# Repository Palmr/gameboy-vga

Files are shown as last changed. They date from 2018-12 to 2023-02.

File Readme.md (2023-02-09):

# FPGA Game Boy Framebuffer

My attempts at hooking in to the Game Boy LCD cable to sniff frame data.

Currently only looking at the Game Boy Pocket as I have one with screen rot and would ideally like to add other output options or replace the screen with something else.

## Requirements

Currently running off an [Lattice Semi](http://www.latticesemi.com) FPGA on a [TinyFPGA BX](https://github.com/tinyfpga/TinyFPGA-BX).

After cloning this repository make sure to pull in the submodule for building/flashing the RTL

```bash
git submodule update --init
```

This should pull in my forked version of the excellent [fpga-tools](https://github.com/pwmarcz/fpga-tools/) submodule by [Paweł Marczewski](https://github.com/pwmarcz).

Required software:

- [Project IceStorm](http:///www.clifford.at/icestorm/)
- [iceBurn](https://github.com/davidcarne/iceBurn)
- GTKWave (for `make sim` target)

## RTL

Experiments documented in [see the rtl/exploration/Readme.md](./rtl/exploration/Readme.md).

Actual code is in the RTL folder currently.

## Devlog

Gameboy MGB (pocket) LCD cable pinout:

	1 - GND
	2 - Control
	3 - Data latch
	4 - Horiz Sync
	5 - Data 0
	6 - Data 1
	7 - Clock
	8 - Alt Sig
	9 - V5
	10 - V3
	11 - V2
	12 - Data latch
	13 - VSYNC
	14 - Vcc (5 volts)
	15 - Alt sign
	16 - V1
	17 - V4
	18 - V5

I connected that to the FPGA and passed the signals through to check the voltages were all okay and the FPGA was registering the signals as expected.

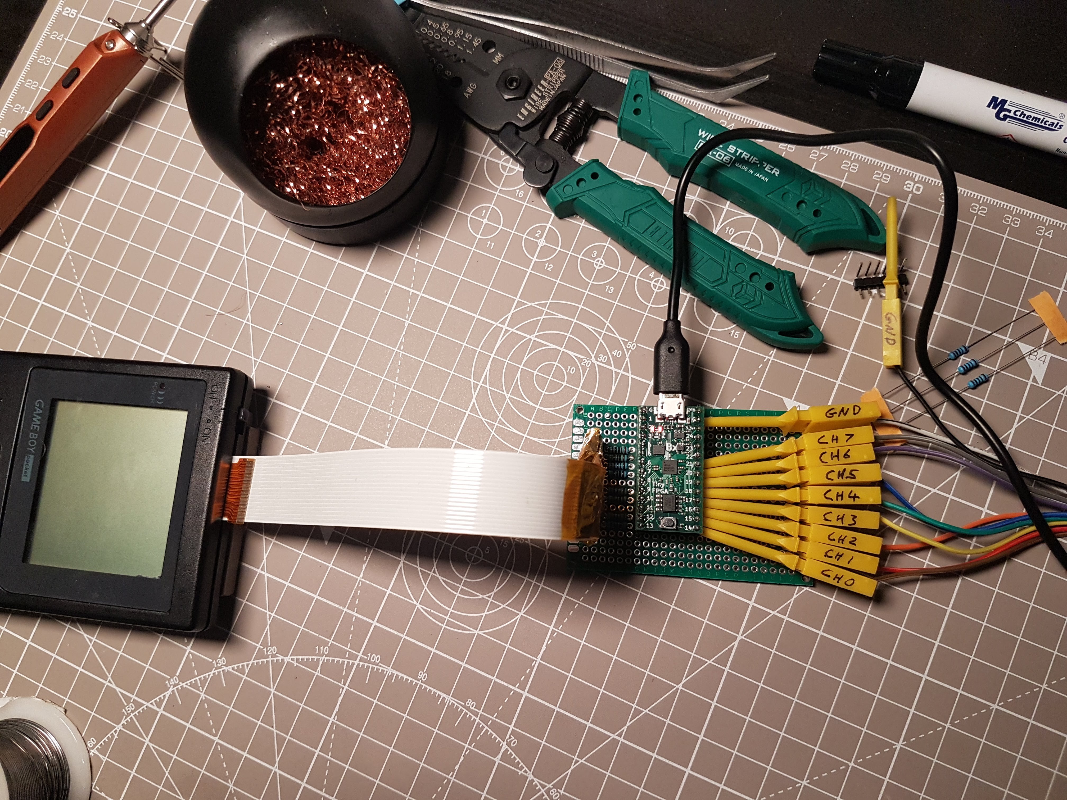
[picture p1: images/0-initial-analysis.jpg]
Initial FPGA passthrough and tracing


Trace from [frame_counter.v](rtl/exploration/frame_counter.v) showing `0x3B` transitions of the `VSYNC` signal per second, aka 59fps:

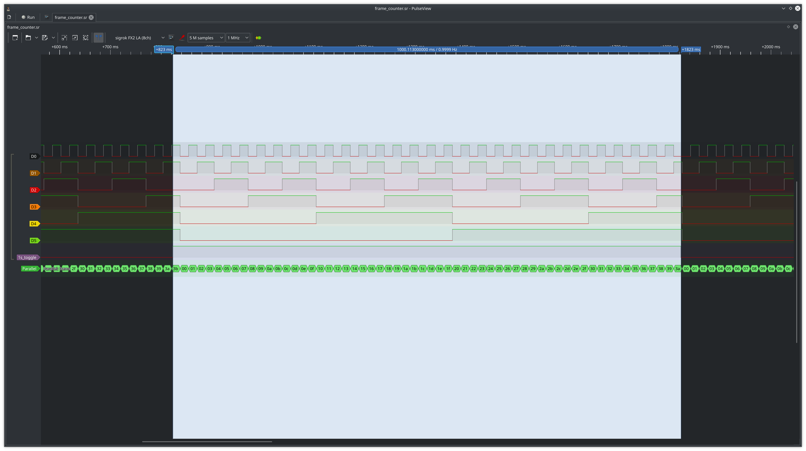
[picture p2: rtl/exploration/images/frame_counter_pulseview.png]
Pulseview screenshot of frame counter


Trace from [pixels_per_frame_counter.v](rtl/exploration/pixels_per_frame_counter.v) showing `0x59FF` pixel clock transitions per `VSYNC`:

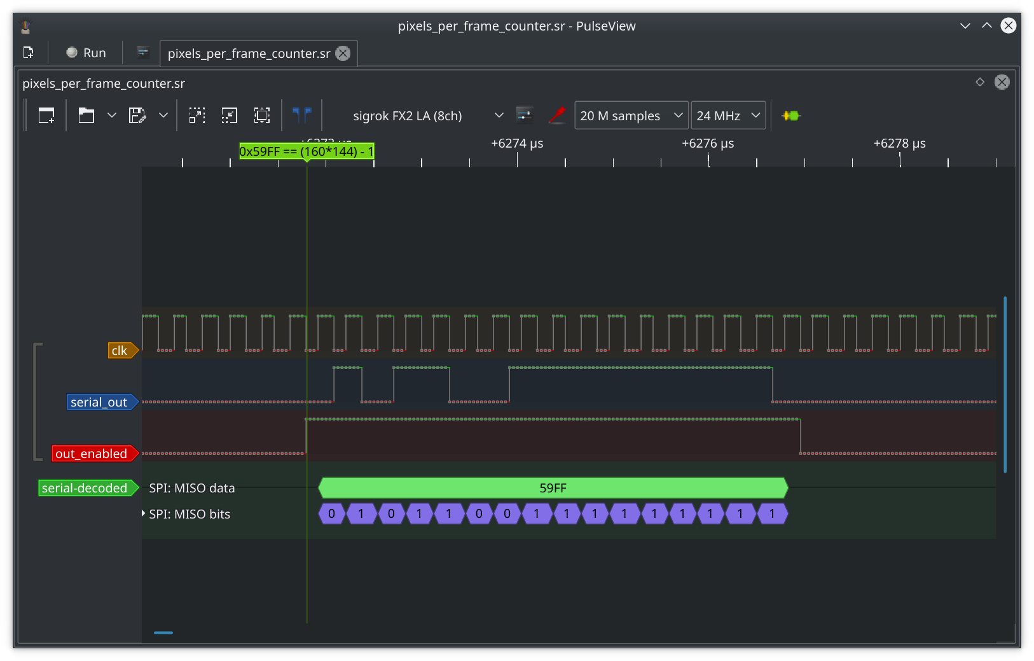
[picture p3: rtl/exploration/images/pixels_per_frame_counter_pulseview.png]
Pulseview screenshot of pixels per frame counter


VGA core started with some timing bars to check my timings and pixel counts added up.

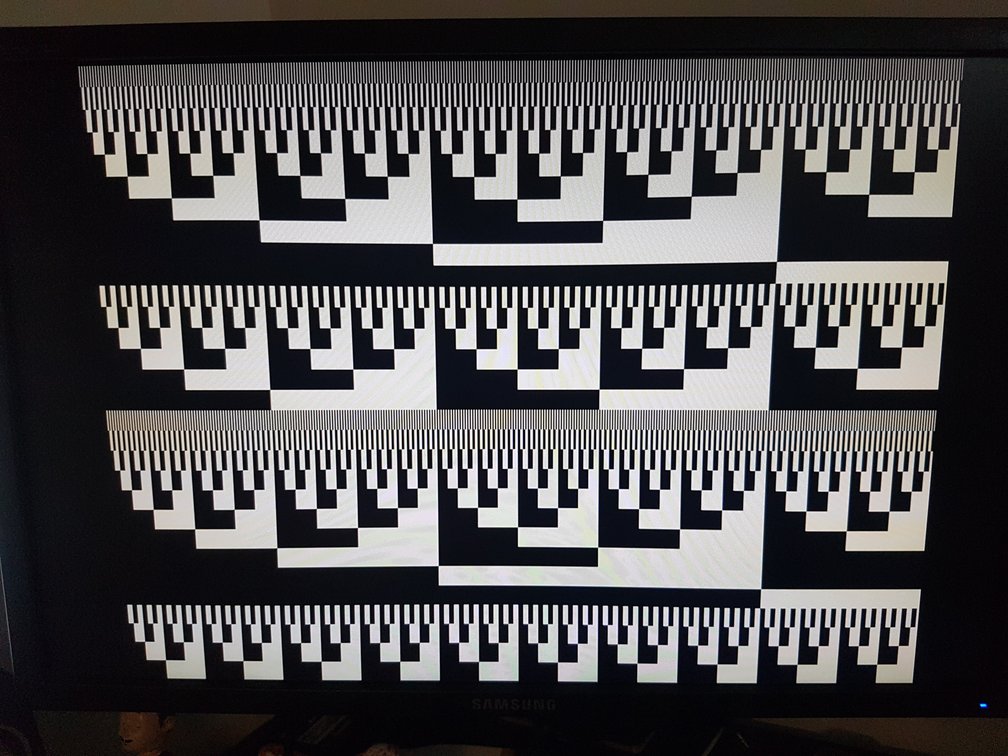
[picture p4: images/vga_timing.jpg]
VGA timing bars


That worked so I moved on to a 2 bit grayscale colour system using resistor values to tweak voltage levels for VGA.

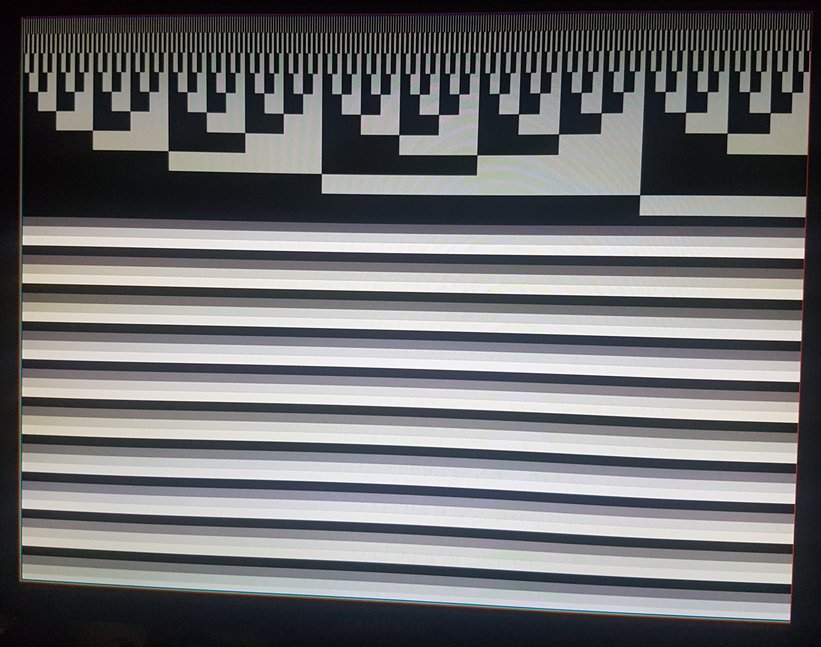
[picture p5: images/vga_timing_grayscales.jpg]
VGA timing bars and grayscale colour bars


By this time my desk is a mess.

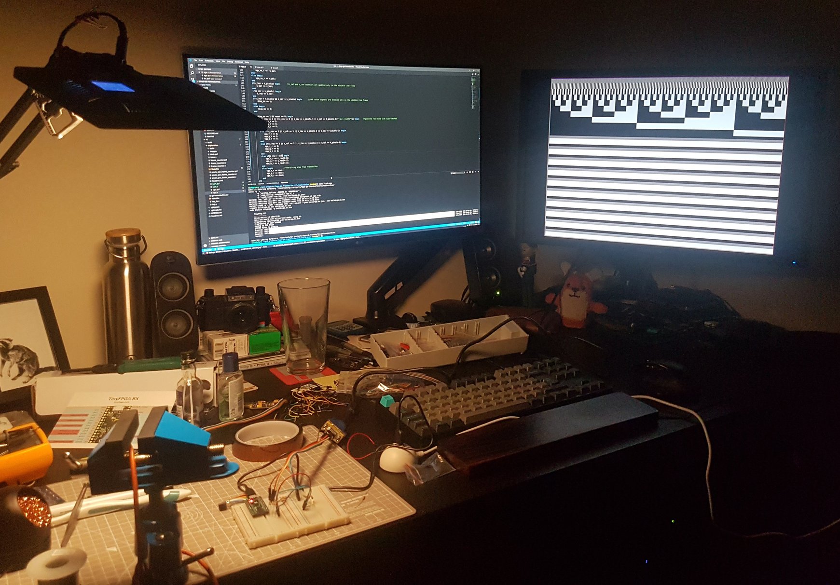
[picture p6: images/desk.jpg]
Messy desk


Protoboard was soldered together for a cleaner setup after breadboarding.

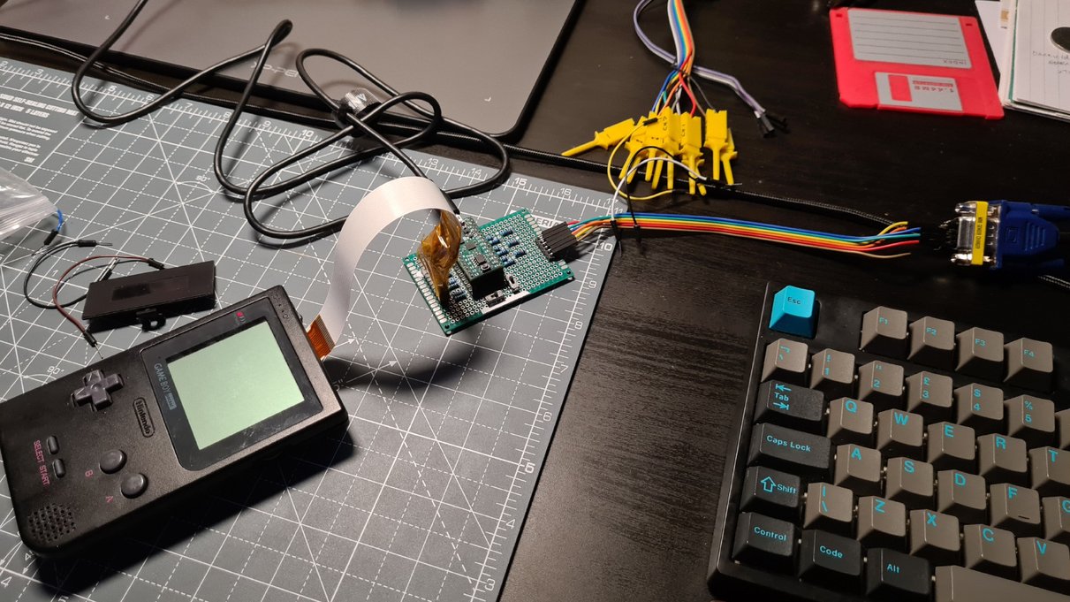
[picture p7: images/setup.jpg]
FPGA protoboard with VGA and GameBoy LCD connection


First attempts at capturing and displaying the framebuffer from the GameBoy LCD showed some severe timing issues.

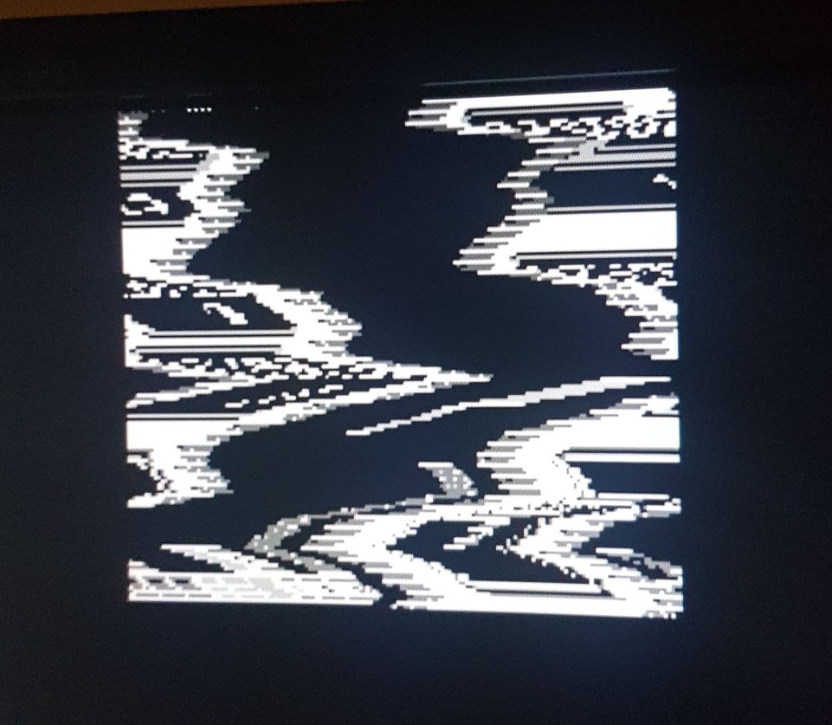
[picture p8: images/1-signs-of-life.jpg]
HSYNC mess


It also showed the colour palette was inverted.

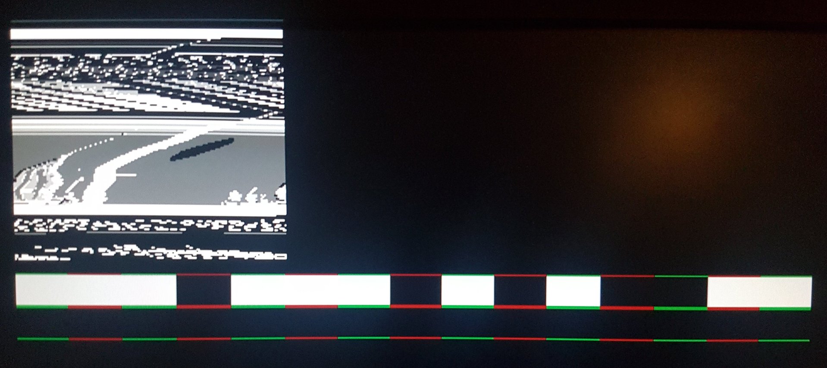
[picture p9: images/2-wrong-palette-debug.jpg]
HSYNC mess & bad palette


Fixing the palette was simple, but finding thr source of the HSYNC skew was tougher.

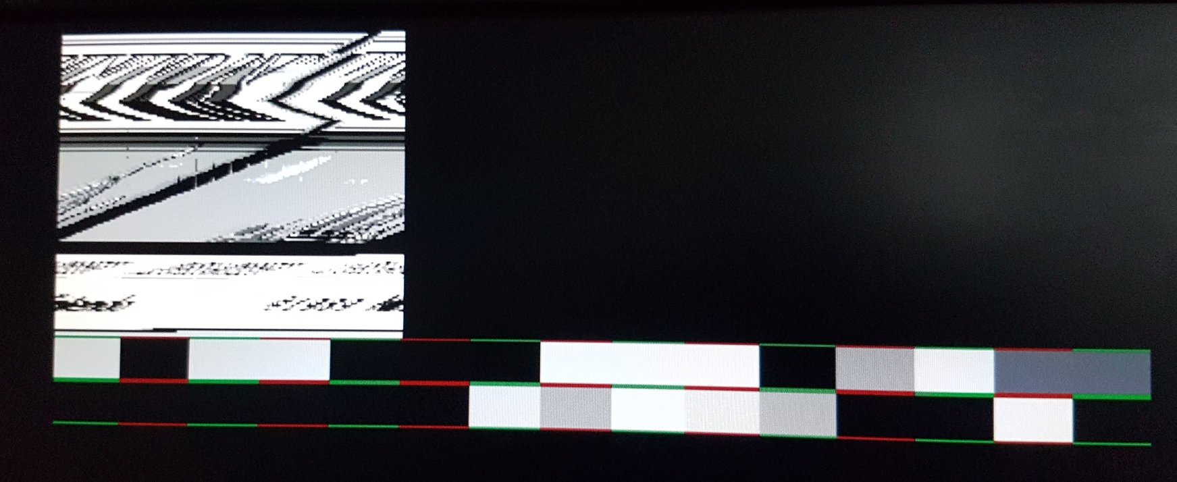
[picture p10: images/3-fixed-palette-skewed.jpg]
HSYNC mess & fixed palette


Eventually traced my HSYNC issues down to a badly terminated HSYNC connection from the LCD. Still the game looked a little slanted, especially at the lower part of the screen.

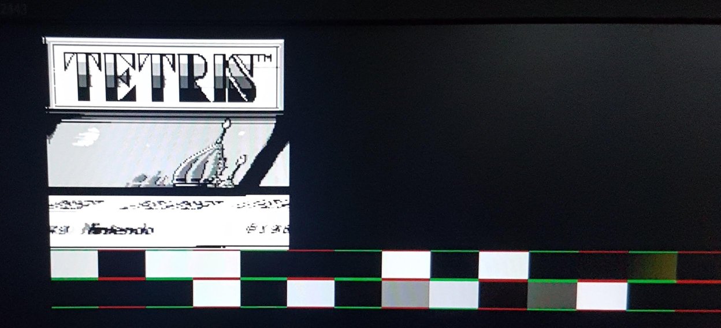
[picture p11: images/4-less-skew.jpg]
Fixed skew, almost


That was down to me incorrectly counting pixels and underfilling lines. With this fixed it's almost passable.

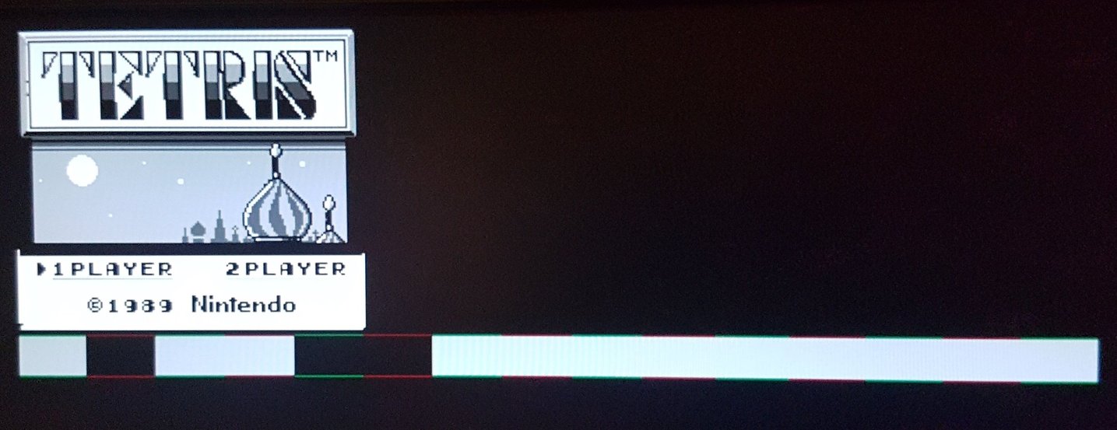
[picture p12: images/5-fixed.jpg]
Tetris title screen displaying correctly


With everything working I could remove my debug information and add a 2x scaling to the display, and centre it to the screen.

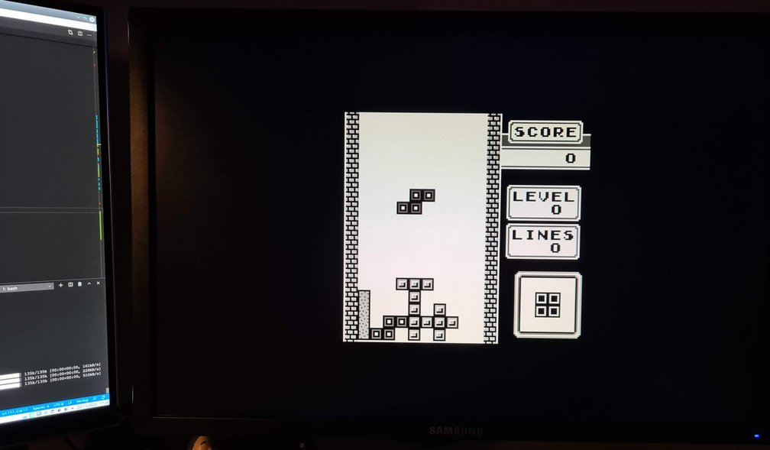
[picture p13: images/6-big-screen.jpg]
Tetrix gameplay from GameBoy to VGA


:tada:

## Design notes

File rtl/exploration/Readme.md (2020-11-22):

# Exploratory RTL

While developing this I sometimes needed to try things out. This folder contains my files.

## blink.v

While doing some dumps of the LCD cable previously I noticed issues with the VSYNC signal. To investigate this further I wanted to get an FPS counter from the cable based on vsync signals seen per second.

I developed on an iCEblink40LP1K devkit which has a 3.33MHz clock by default, to get the "per second" figure to a reasonable degree of accuracy I wrote blink.v to toggle an LED every second.

I used a logic analyser to check how accurate the timing was and tweaked the CLOCKS_PER_SEC parameter to hone in on a 1 second LED_STATE toggle.

### Building

```bash
make flash-blink
```

## frame_counter.v

Counts VSYNC signal per second, outputting counter on pins [B26, B27, A38, B29, B30, B31, A43, B34] and the second toggle on LED4/pin A25

Frame counter pulseview

In the above screenshot I could confirm I was seeing 0x3B (59) frames per second.

### Building

```bash
make flash-frame_counter
```

## pixels_per_frame_counter.v

Counts PIXEL_CLOCK falling per VSYNC, outputting counter in serial form at the fpga clock rate.

Pixels per frame counter pulseview

In the above screenshot I could confirm I was seeing 0x59FF (23039 == (160*144) - 1) the expected number of pixels

### Building

```bash
make flash-pixels_per_frame_counter
```

## vga_test.v

Testing VGA

### Building

```bash
make flash-vga_test
```

## uart.v

Testing UART

### Building

```bash
make flash-uart
```

## vga_test.v

Testing VGA with a gb screen sized framebuffer and optional 2x scaling

### Building

```bash
make flash-vga_frame_buffer_test
```

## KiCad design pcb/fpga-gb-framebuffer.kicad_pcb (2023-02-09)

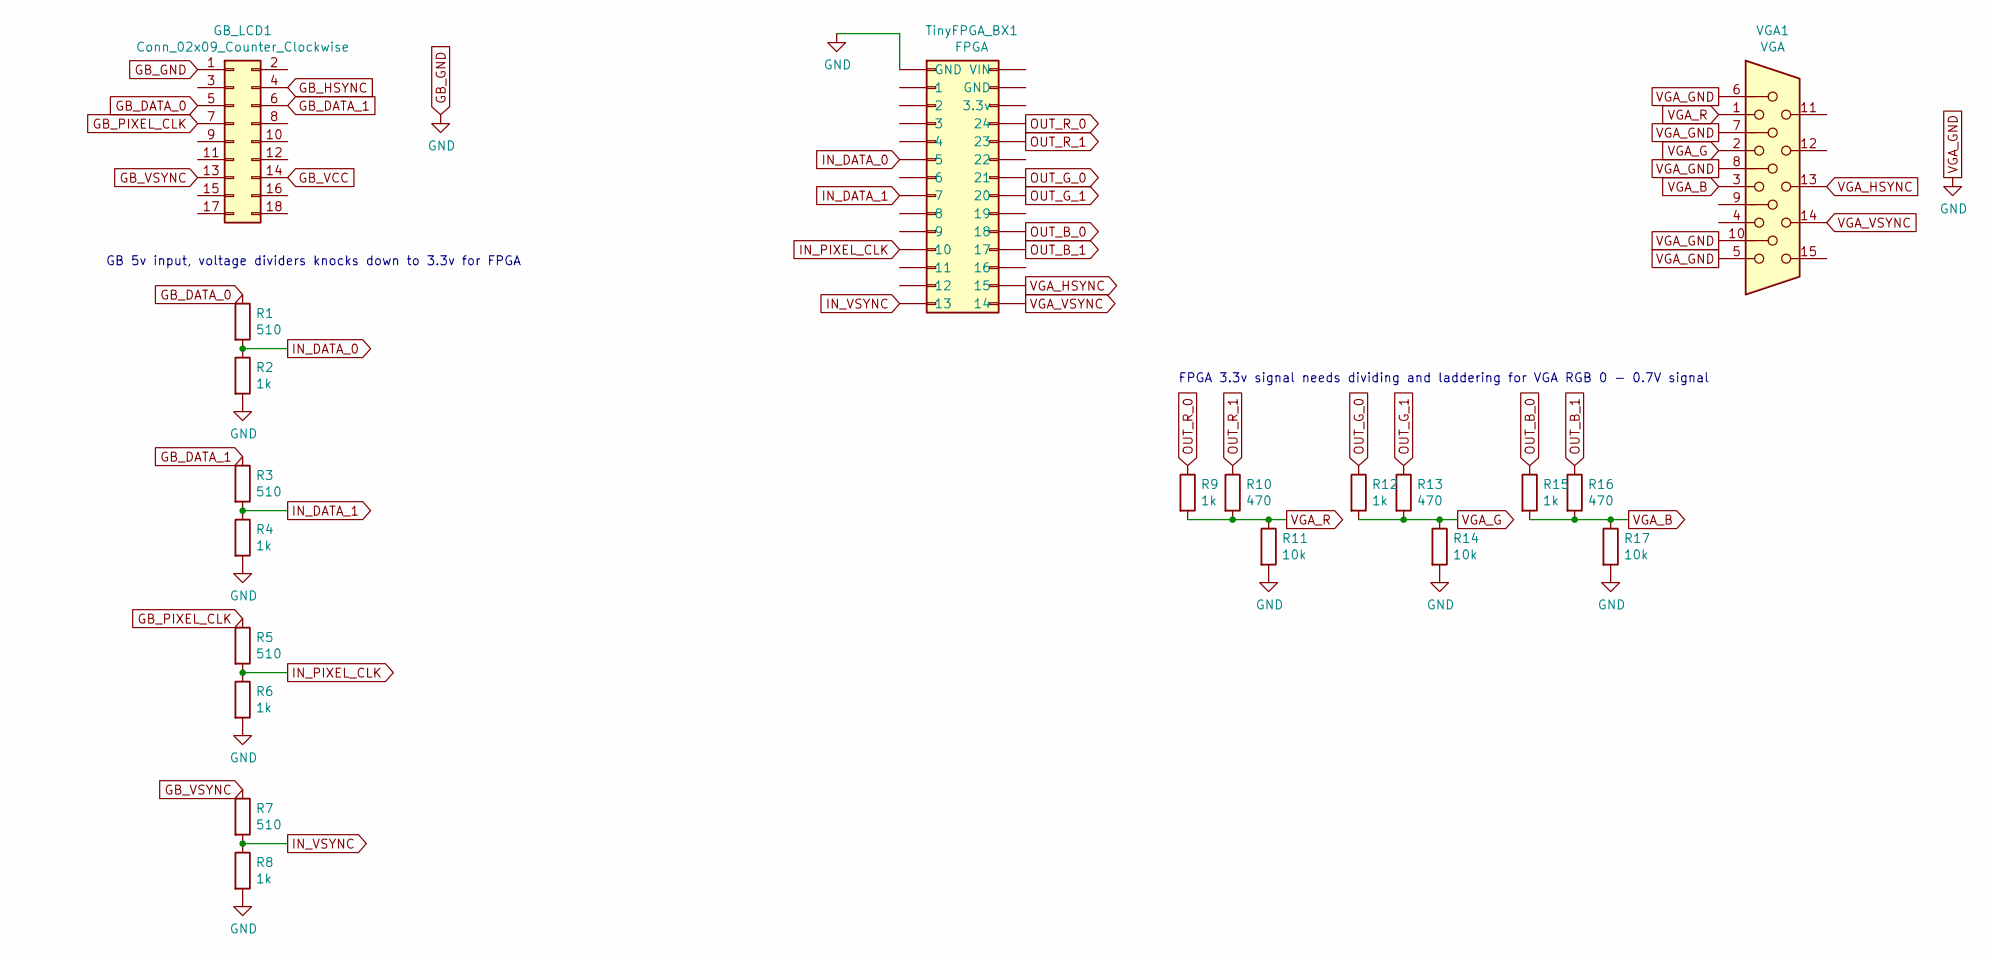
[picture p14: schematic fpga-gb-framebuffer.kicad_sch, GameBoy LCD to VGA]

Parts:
GB_LCD1: Conn_02x09_Counter_Clockwise; PinHeader_2x09_P2.54mm_Vertical
R1, R3, R5, R7: 510; R_Axial_DIN0204_L3.6mm_D1.6mm_P7.62mm_Horizontal
R2, R4, R6, R8, R9, R12, R15: 1k; R_Axial_DIN0204_L3.6mm_D1.6mm_P7.62mm_Horizontal
R10, R13, R16: 470; R_Axial_DIN0204_L3.6mm_D1.6mm_P7.62mm_Horizontal
R11, R14, R17: 10k; R_Axial_DIN0204_L3.6mm_D1.6mm_P7.62mm_Horizontal
TinyFPGA_BX1: FPGA; TinyFPGA_BX
VGA1: VGA; DSUB-15-HD_Female_Vertical_P2.29x1.98mm_MountingHoles

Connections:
GB_DATA_0: GB_LCD1.5, R1.1
GB_DATA_1: GB_LCD1.6, R3.1
GB_GND: GB_LCD1.1, R2.2, R4.2, R6.2, R8.2, R11.2, R14.2, R17.2, TinyFPGA_BX1.1 (GND), VGA1.5, VGA1.6, VGA1.7, VGA1.8, VGA1.10
GB_HSYNC: GB_LCD1.4
GB_PIXEL_CLK: GB_LCD1.7, R5.1
GB_VCC: GB_LCD1.14
GB_VSYNC: GB_LCD1.13, R7.1
IN_DATA_0: R1.2, R2.1, TinyFPGA_BX1.6 (5)
IN_DATA_1: R3.2, R4.1, TinyFPGA_BX1.8 (7)
IN_PIXEL_CLK: R5.2, R6.1, TinyFPGA_BX1.11 (10)
IN_VSYNC: R7.2, R8.1, TinyFPGA_BX1.14 (13)
OUT_B_0: R15.1, TinyFPGA_BX1.19 (18)
OUT_B_1: R16.1, TinyFPGA_BX1.18 (17)
OUT_G_0: R12.1, TinyFPGA_BX1.22 (21)
OUT_G_1: R13.1, TinyFPGA_BX1.21 (20)
OUT_R_0: R9.1, TinyFPGA_BX1.25 (24)
OUT_R_1: R10.1, TinyFPGA_BX1.24 (23)
VGA_B: R15.2, R16.2, R17.1, VGA1.3
VGA_G: R12.2, R13.2, R14.1, VGA1.2
VGA_HSYNC: TinyFPGA_BX1.16 (15), VGA1.13
VGA_R: R9.2, R10.2, R11.1, VGA1.1
VGA_VSYNC: TinyFPGA_BX1.15 (14), VGA1.14

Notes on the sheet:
GB 5v input, voltage dividers knocks down to 3.3v for FPGA
FPGA 3.3v signal needs dividing and laddering for VGA RGB 0 - 0.7V signal

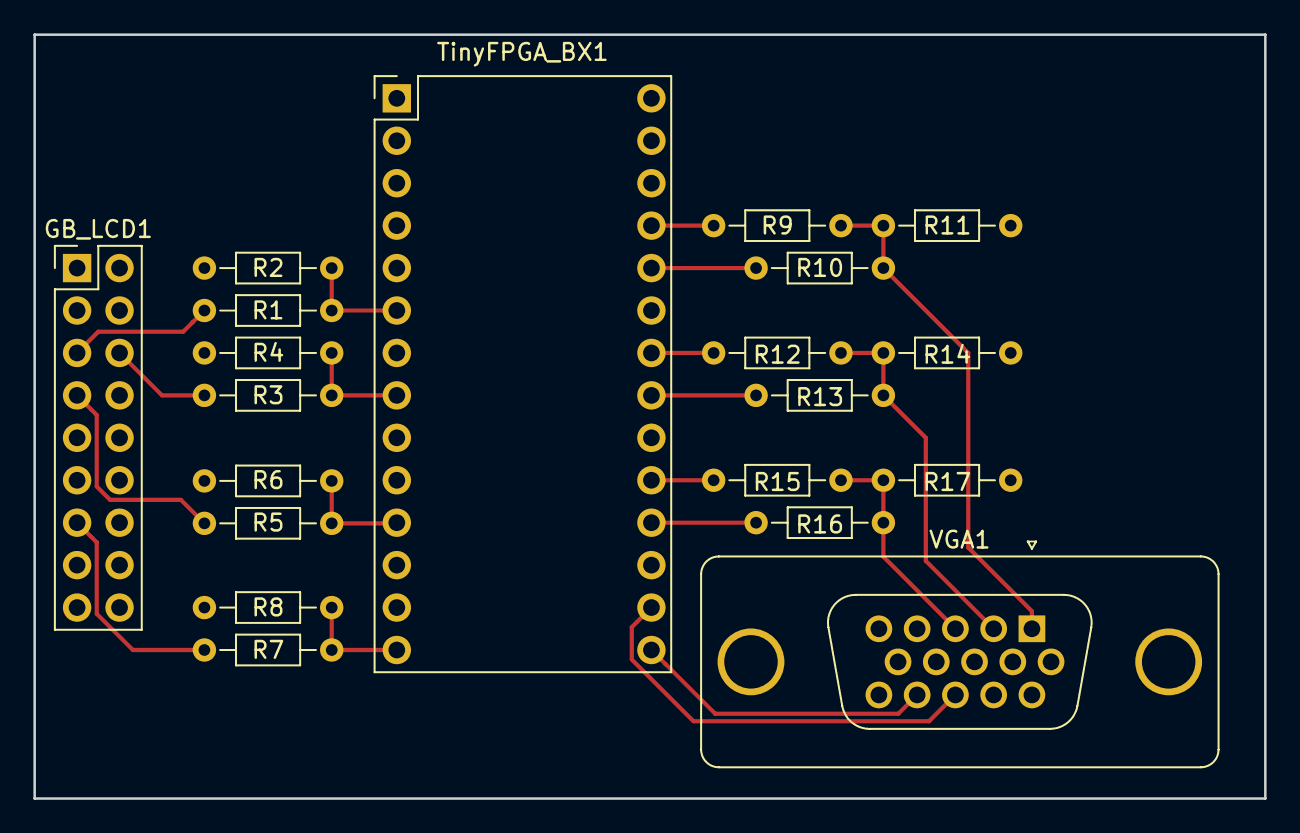
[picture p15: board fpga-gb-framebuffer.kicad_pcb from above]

Board: 2 copper layers, 73.7 x 45.7 mm, 20 parts (0 on the bottom side), 20 nets.

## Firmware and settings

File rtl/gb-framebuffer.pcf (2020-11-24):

## INPUTS

# FPGA clock
set_io CLK_16MHz    B2

# 2x Scaling
set_io scaling_x2   A2  # BX:1

# GB LCD Inputs
set_io GB_DAT[0]    C1  # BX:5  <- white <- MGB LCD pin 5
set_io GB_DAT[1]    D1  # BX:7  <- white <- MGB LCD pin 6
set_io GB_PX_CLK    G2  # BX:10 <- orange <- MGB LCD pin 7
set_io GB_HSYNC     J1  # BX:12 <- n/a <- MGB LCD pin 4 # Currently not connected on board
set_io GB_VSYNC     H2  # BX:13 <- yellow <- MGB LCD pin 13

## OUTPUTS

set_io vga_r[0]     A6  # RED BX:24 -> 1k/10k -> VGA:1
set_io vga_r[1]     B6  # RED BX:23 -> 470/10k -> VGA:1

set_io vga_g[0]     B7  # GREEN BX:21 -> 1k/10k -> VGA:2
set_io vga_g[1]     A8  # GREEN BX:20 -> 470/10k -> VGA:2

set_io vga_b[0]     A9  # BLUE BX:18 -> 1k/10k -> VGA:3
set_io vga_b[1]     C9  # BLUE BX:17 -> 470/10k -> VGA:3

set_io vga_hs       D9  # HSYNC BX:15 -> purple/orange -> VGA:13
set_io vga_vs       H9  # VSYNC BX:14 -> yellow -> VGA:14

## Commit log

2018-12-18 Added a pixels per frame counter
2019-01-01 VGA framebuffer test
2019-01-06 Add UART test
2019-01-06 First stab, sync issues however
    [gb-framebuffer.pcf]
2019-01-13 kicad first tinyfpga board
    [fpga-gb-framebuffer.kicad_pcb, fpga-gb-framebuffer.sch]
2019-01-16 Updated PCB design
    [fpga-gb-framebuffer.kicad_pcb, fpga-gb-framebuffer.sch]
2019-01-16 Updated framecounter for TinyFPGA BX
2019-01-16 Schematic update with tinyfpga symbol and pin assignment update for VGA
    [fpga-gb-framebuffer.kicad_pcb, fpga-gb-framebuffer.sch]
2019-01-16 Fixed fab and silskcreen layouts
    [fpga-gb-framebuffer.kicad_pcb]
2019-01-16 kicad project update
    [fpga-gb-framebuffer.kicad_pcb]
2019-01-17 Updated for kicad design
2020-11-24 Empty the empty-framebuffer
2023-02-09 refresh pcb with newer kikad
    [fpga-gb-framebuffer.kicad_pcb, fpga-gb-framebuffer.kicad_sch]
